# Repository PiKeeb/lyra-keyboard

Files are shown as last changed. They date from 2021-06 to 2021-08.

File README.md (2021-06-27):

# lyra-keyboard
Lyra keyboard



Case design by **alexbarb**

PCB design by **KGOH** & **ILWrites**

Lyra

### Design features:
* Size: 338,5 × 104 × 27 mm (13.3 × 4 × 1.1 inch)
* Universal design, accommodates Alpha and Beta PCBs
* 6° typing angle
* Alpha or Beta hot-swap PCB (USB Type C connector)
* One RGB LED
* Fully programmable (supports QMK)
* 1.5 mm plate (only PCB-mounted stabilizers)
* 6.25U off-center spacebar
* M2 screws
* Recesses on the bottom of the case for the rubber bumpers

### Layout variations

**Alpha 58/62 MX Hot-swap PCB**
Alpha PCB Layout
Alpha PCB Back

Alpha PCB Front
___
**Beta 58/62 MX Hot-swap PCB**
Beta PCB Layout
Beta PCB Back

Beta PCB Front

### Prototype Photos

Lyra1
Lyra2
Lyra3
LyraLed

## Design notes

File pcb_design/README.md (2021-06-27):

# lyra-keyboard/pcb_design

PCB design has been made in **KiCad**

Version: (5.99.0-10161-g3a96736b1f), release build

Please, use the version above or newer.

**gerber** folder for each board contains the files needed for PCB production.

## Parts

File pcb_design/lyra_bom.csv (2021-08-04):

Id | Designator | Package | Quantity | Type | Termination | Package | Designation | Parameters (Rating/Tolerance/etc) | Description | Manufacturer | Part Number
1 | C1,C2 | C_0805 | 2 | Capacitor | SMD | 0805 | 22p | 50V ±5% | Capacitor SMD 0805 22pF 50V ±5% | Samsung Electro-Mechanics | CL21C220JBANNNC
2 | C3 | C_0805 | 1 | Capacitor | SMD | 0805 | 1u | 50V ±5% | Capacitor SMD 0805 1uF 50V ±5% | Samsung Electro-Mechanics | CL21B105KBFNNNE
3 | C5,C6,C4,C7 | C_0805 | 4 | Capacitor | SMD | 0805 | 0.1u | 50V ±5% | Capacitor SMD 0805 0.1uF 50V ±5% | CCTC | TCC0805X7R104K500DT
4 | C8 | C_0805 | 1 | Capacitor | SMD | 0805 | 4.7u | 50V ±5% | Capacitor SMD 0805 4.7uF 50V ±5% | Walsin Tech Corp | 0805X475K500CT
5 | D10,D11,D31,D33,D1,D2,D4,D3,D7,D5,D6,D8,D9,D53,D71,D65,D69,D62,D64,D59,D70,D57,D58,D56,D60,D41,D44,D49,D39,D46,D50,D38,D47,D51,D55,D42,D48,D34,D32,D35,D37,D36,D40,D20,D23,D28,D18,D29,D16,D12,D24,D27,D13,D14,D26,D21,D22,D15,D25,D17,D19,D43 | D_0805_2012Metric_Pad1.15x1.40mm_HandSolder | 62 | Switching Diode | SMD | 0805 | D | 75V 150mA 1.25V @ 100mA 4ns | Switching Diode SMD 0805 75V 150mA 1.25V @ 100mA 4ns | LIZ Elec | CD4148WSP
6 | D73 | LED_SK6812MINI_PLCC4_3.5x3.5mm_P1.75mm | 1 | LED | SMD | 3535 | WS2812B-Mini |  | LED SMD 3535 WS2812B-Mini | Worldsemi | WS2812B-Mini
7 | F1 | R_0805 | 1 | PTC Resettable Fuse | SMD | 0805 | Polyfuse | 6V 1A 100ms | PTC Resettable Fuse SMD 0805 6V 1A 100ms | TLC Electronic | TLC-PSMD050
9 | J1 | HRO-TYPE-C-31-M-12 | 1 | USB Type C Receptacle | SMD/THT |  | HRO-TYPE-C-31-M-12 |  | USB Type C Receptacle SMD/THT | Korean HROparts | TYPE-C-31-M-12
10 | K10,K37,K20,K47,K4,K31,K34,K64,K55,K40,K23,K65,K66,K67,K53,K35,K70,K69,K28,K25,K9,K13,K14,K17,K12,K18,K22,K24,K32,K15,K27,K16,K3,K54,K30,K11,K41,K5,K7,K6,K63,K26,K2,K71,K33,K68,K58,K36,K1,K21,K8,K60,K48,K19,K29,K61,K62,K45,K46,K50,K38,K51,K52,K39,K42,K49,K43,K56,K57,K59,K44 | Kailh_socket3 | 71 | Key Socket | SMD |  | KEYSW |  | Key Socket SMD | Kailh | CPG151101S11
11 | R1,R2 | R_0805 | 2 | Chip Resistor | SMD | 0805 | 22 | 1/8W ±5% | Chip Resistor SMD 0805 22Ohm 1/8W ±5% | BOURNS | CR0805-FX-22R0ELF
12 | R3,R4 | R_0805 | 2 | Chip Resistor | SMD | 0805 | 5.1k | 1/8W ±5% | Chip Resistor SMD 0805 5.1kOhm 1/8W ±5% | UNI-ROYAL(Uniroyal Elec) | 0805W8J0512T5E
13 | R5,R6 | R_0805 | 2 | Chip Resistor | SMD | 0805 | 10k | 1/8W ±5% | Chip Resistor SMD 0805 10kOhm 1/8W ±5% | UNI-ROYAL(Uniroyal Elec) | 0805W8F1002T5E
14 | SW1 | SW_SPST_TL3342 | 1 | Tactile Switch | SMD | TL3342 | SW_PUSH |  | Tactile Switch SMD TL3342 | Korean HROparts | K2-1187SQ-A4SW-06
15 | U1 | ATMEGA32U4 | 1 | MCU | SMD | TQFP-44 | ATmega32U4 |  | MCU SMD TQFP-44 | Microchip Tech | ATMEGA32U4-AU
16 | U2 | USBLC6-2SC6 | 1 | USB ESD Protection IC | SMD | SOT-23-6 | USBLC6-2SC6 |  | USB ESD Protection IC SMD SOT-23-6 | STMicro | USBLC6-2SC6
17 | X1 | crystal_FA238-TSX3225 | 1 | Crystal Oscilator | SMD | TSX-3225 | XTAL_GND | 16MHz ±10ppm | Crystal Oscilator SMD TSX-3225 16MHz ±10ppm | Seiko Epson | X1E000021061300

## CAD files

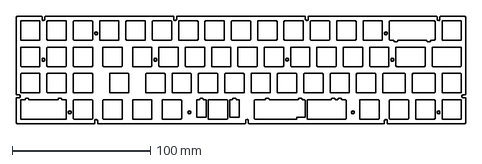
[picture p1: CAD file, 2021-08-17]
case_design/Lyra_beta_plate_v2_325,2x77.55mm.dxf
325.2 x 77.5 mm

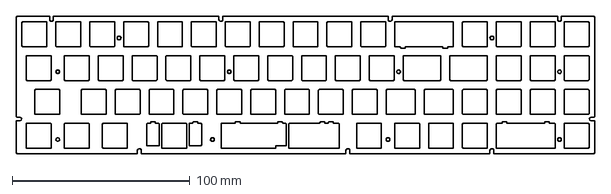
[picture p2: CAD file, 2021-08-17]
case_design/Lyra_alpha_plate_v2_325,2x77.55mm.dxf
325.2 x 77.5 mm

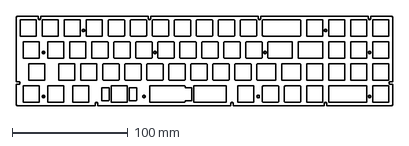
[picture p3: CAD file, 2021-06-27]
case_design/Lyra_Alpha_Plate_325.4x77.75 mm.dxf
325.4 x 77.7 mm

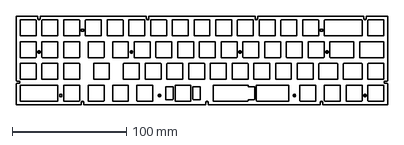
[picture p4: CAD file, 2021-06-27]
case_design/Lyra_Beta_Plate_325.4x77.75 mm.dxf
325.4 x 77.7 mm

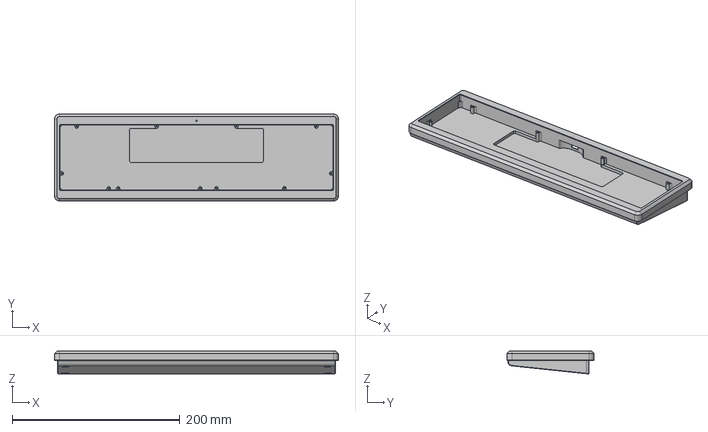
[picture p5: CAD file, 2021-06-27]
case_design/lyra-keyboard.step
338.5 x 103.9 x 27.4 mm
углы

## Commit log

2021-06-27 First commit with files
    Added files, licence and readme
    [Lyra_Alpha_Plate_325.4x77.75 mm.dxf, Lyra_Beta_Plate_325.4x77.75 mm.dxf, lyra-keyboard.step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]
2021-08-04 Updated mounting holes
    Updated mounting holes to not touch the pads of the hotswap sockets.
    [lyra_alpha-B_Cu.gbl, lyra_alpha-B_Mask.gbs, lyra_alpha-B_Paste.gbp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]
2021-08-04 Added the case file with Lyra logo
    Added the case file with Lyra logo on the bottom.
2021-08-04 Added BOM
    [lyra_bom.csv]
2021-08-17 Changed the plate dxf's to v2
    [Lyra_alpha_plate_v2_325,2x77.55mm.dxf, Lyra_beta_plate_v2_325,2x77.55mm.dxf]

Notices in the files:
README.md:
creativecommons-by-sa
